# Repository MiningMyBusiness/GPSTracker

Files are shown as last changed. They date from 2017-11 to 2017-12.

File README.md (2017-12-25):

# GPS Tracker
Collection, visualization, and analysis of GPS data gathered with a homemade GPS module.

## Motivation
The concept of connectivity recives a lot of attention from a wide variety of fields. While we tend to reserve the main discussions about connectivity to the digital realm, I find myself drawn to the concept of connectivity in the physical world. Where we travel everyday and how we get there directly influences what we are exposed to and what is exposed to us. This has consequences for everything from disease epidemics to advertising. Moreover, such a record of movement would allow individuals to create an auxiliary memory of the history of places visited with great detail. Having access to this kind of information could have the potential for changing our sense of ourselves. 

For these reasons, I decided to track everywhere I go every day. I hope that this will give me an idea about how I move and where I go in this city, this country, and this world. Moreover, it will be a direct record of everywhere I have gone. I want to extract from this data the balance between my walking and using vehicular transport, my carbon footprint, and the geographical web in which I live my life. 

## Hardware
The homemade GPS module consists of Arduino Nano, an SD card module, an SD card, a passive ceramic GPS module, a 3.7V to 5V boost converter, and a LiPo battery. A schematic is shown below but more detail can be found in the [Hardware](https://github.com/MiningMyBusiness/GPSTracker/raw/master/Hardware) folder of the repository. The code used to program the Arduino can be found in the [Code](https://github.com/MiningMyBusiness/GPSTracker/raw/master/Code) folder of this repository.

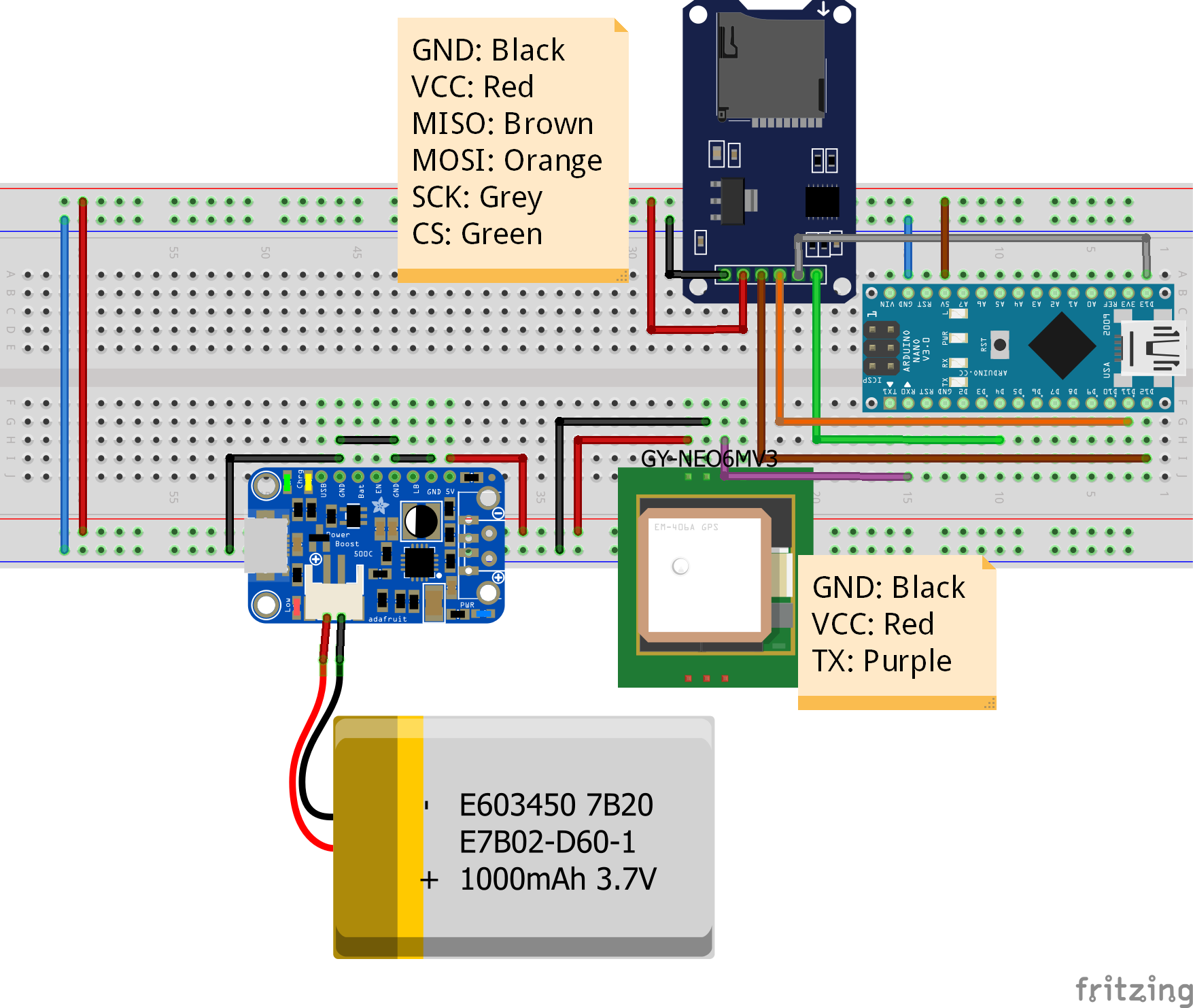
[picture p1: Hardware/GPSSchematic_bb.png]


I chose to make a homemade GPS over using the GPS in my smart phone. The cons of doing this include having to build and carry another piece of hardware. The pros include not having to worry about data plans, about your cell phone battery dying, about how your data may be held hostage or used by apps like [Swarm](https://en.wikipedia.org/wiki/Swarm_(app)), and the opportunity to learn something new. Additionally, since this homemade GPS module doesn't rely on cellular phone networks, it can track me anywhere in the world including in the middle of an ocean or a desert (assuming I go there). 

### Pilot hardware
I implemented the beta version of this hardware in a carboard Sparkfun box shown below (the mouse is in the image for comparison). This was adequately portable to collect pilot data. Use the mouse in the photo for size comparison.

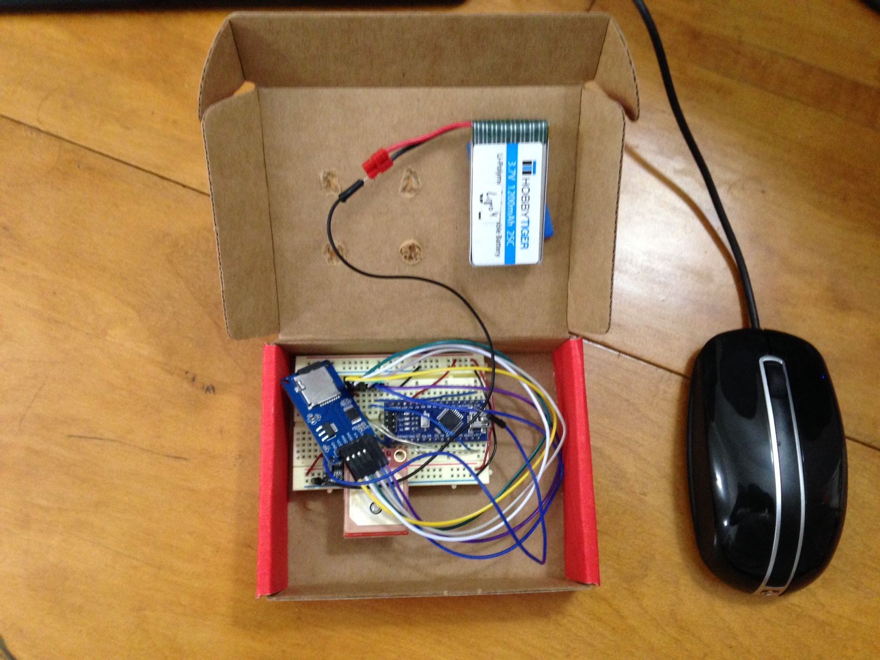
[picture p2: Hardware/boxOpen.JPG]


### Prototype hardware
I also made a much smaller version which I took with me when I travelled out of the country. The battery is blocking the view to the remainder of the parts.

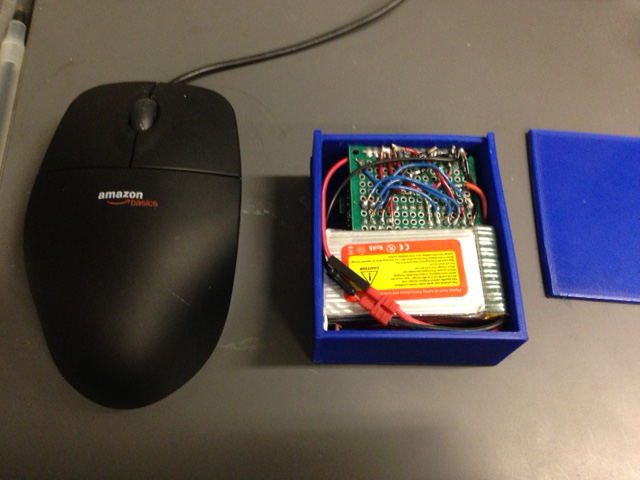
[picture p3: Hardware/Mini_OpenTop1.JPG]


More pictures of the smaller version and the .stl files for the 3D model of the box are provided in the [Hardware](https://github.com/MiningMyBusiness/GPSTracker/raw/master/Hardware) folder of the repository. This was tested on mountain roads between Bogota, Chaochi, and Ubaque in Colombia. These roads often do not have very dependable cell or data service. However, the main towns are well connected. 

## Data
The GPS module transmits recieved data to the Arduino. The Arduino writes this data to a text file in the SD card. Some lines in the text file might look like the following:

$GPRMC,070750.00,A,4200.31462,N,08739.74022,W,0.980,,251017,,,A*64 <br />
$GPVTG,,T,,M,0.980,N,1.815,K,A*2F <br />
$GPGGA,070750.00,4200.31462,N,08739.74022,W,1,03,4.76,257.7,M,-33.8,M,,*6D <br />
$GPGSA,A,2,16,27,08,,,,,,,,,,4.86,4.76,1.00*07 <br />
$GPGSV,1,1,04,08,68,076,33,16,13,068,35,27,34,047,23,33,04,102,33*70 <br />
$GPG076,33,16,13,068,34,27,34,047,23,33,04,102,32*70 <br />
$GPGLL,4200.31735,N,08739.74210,W,070755.00,A,A*7B <br />

Please take a look at the [Code](https://github.com/MiningMyBusiness/GPSTracker/raw/master/Code) in the repo to see how to make sense of this data. There is a [Python script](https://github.com/MiningMyBusiness/GPSTracker/raw/master/Code/gpsDataExtractor.py) in the [Code](https://github.com/MiningMyBusiness/GPSTracker/raw/master/Code) folder of the repository that parses through this data and organizes the date, time, latitude and longitude into lists. Then plots this data onto a Google roadmap and saves to an .html with zoom functionality. 

### Pilot data
I collected some data with the pilot hardware around Chicago as I went to work or went out to eat. Open the [html file](https://rawgit.com/MiningMyBusiness/GPSTracker/master/Results/mymap.html) to explore the dataset but I've also provided a static screenshot of the map below. 

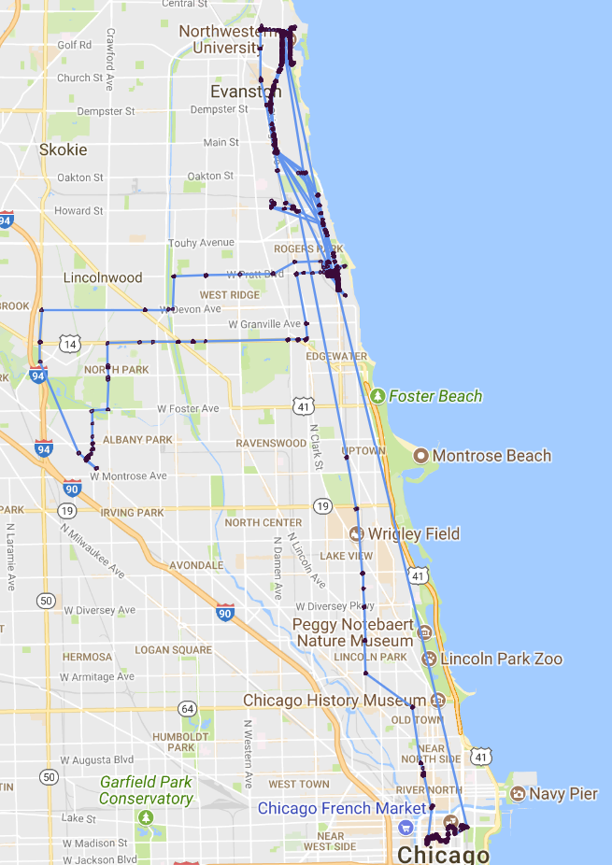
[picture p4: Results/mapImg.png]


### Data collected with prototype 
I took the smaller prototype in the blue box with me on my trip to Bogota, Colombia. I've provided a static screenshot of the map below from my trip to Colombia. Note that it is able to track in the middle of the mountains where there is poor cell/data service. 

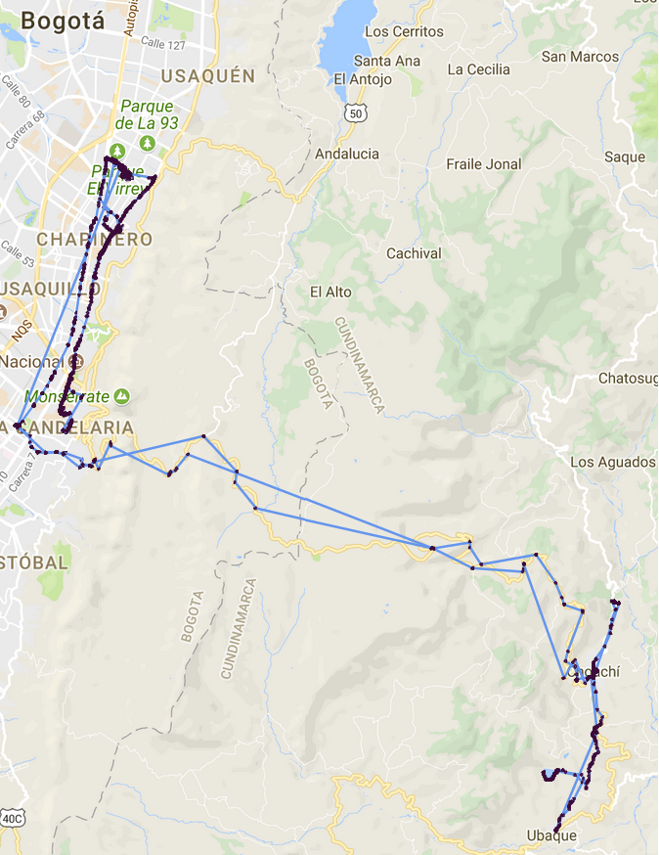
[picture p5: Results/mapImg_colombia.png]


## Work in progress
The next steps involve breaking this data into trips taken by day. Then using the speed of movement I can determine if I was walking or on vehicular transport. Potentially, by using locations where data is collected I can also determine if I was using the L-train.

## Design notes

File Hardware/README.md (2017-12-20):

# Hardware build descriptions
This folder and ReadMe contains relevant information about how to build the GPS module. 

### Parts list
To build the GPS module as described here you will need the following parts:

1. [Arduino Nano](https://www.amazon.com/gp/product/B0713XK923/ref=oh_aui_search_detailpage?ie=UTF8&psc=1)
2. [GPS module](https://www.amazon.com/gp/product/B01AW5QYES/ref=oh_aui_search_detailpage?ie=UTF8&psc=1)
3. [SD card module](https://www.amazon.com/gp/product/B01JYNEX56/ref=oh_aui_search_detailpage?ie=UTF8&psc=1)
4. [SD card](https://www.amazon.com/SanDisk-Memory-SDSDUN-008G-G46-Newest-Version/dp/B00M55BS5O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)
5. [3.7V Lipo battery](https://www.amazon.com/gp/product/B01HG7TYNI/ref=oh_aui_detailpage_o03_s00?ie=UTF8&psc=1)
6. [3.7V to 5V boost converter](https://www.amazon.com/gp/product/B01LW57OUM/ref=oh_aui_detailpage_o07_s00?ie=UTF8&psc=1)

Each part name is a link to the Amazon page for the parts I used to make my module. However, you do not need to adhere exactly to these parts.

### Schematic
The images below represent the wiring of all components in two different ways.

1. A breadboard view with cartoon representation of components made with [Fritzing](http://fritzing.org/home/).


2. A circuit diagram of the wiring of components also made with Fritzing. 
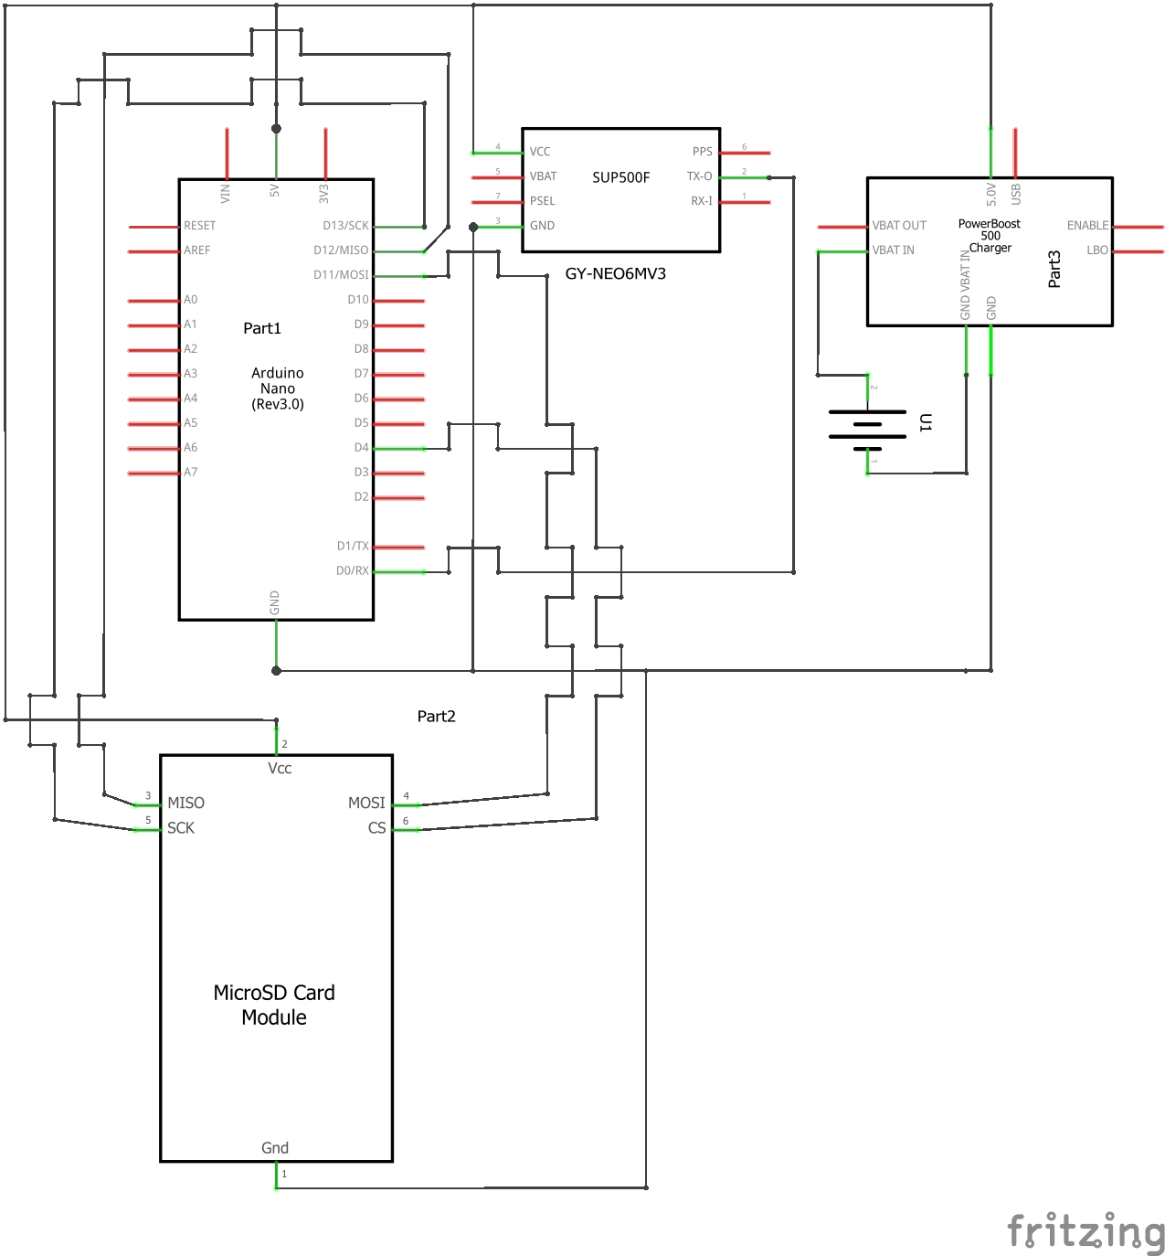
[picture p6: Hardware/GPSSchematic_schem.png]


I used a different 3.7V to 5V boost converter than the one shown in the schematic (link is provided in parts list above) which was a lot simpler and cheaper. 

IMPORTANT NOTE: Do not have the GPS module powered and connected to the RX pin of the Arduino when uploading code onto the Arduino. This will interfere with uploading code onto the Arduino. Power the GPS module after the code has been uploaded onto the Arduino. 

### Initial pilot version
I've attached some images which show the prototype I made to collect some pilot data and test feasibility of this project. The computer mouse in the image provides a size comparison with the prototype. 

1. Innards


2. Top view
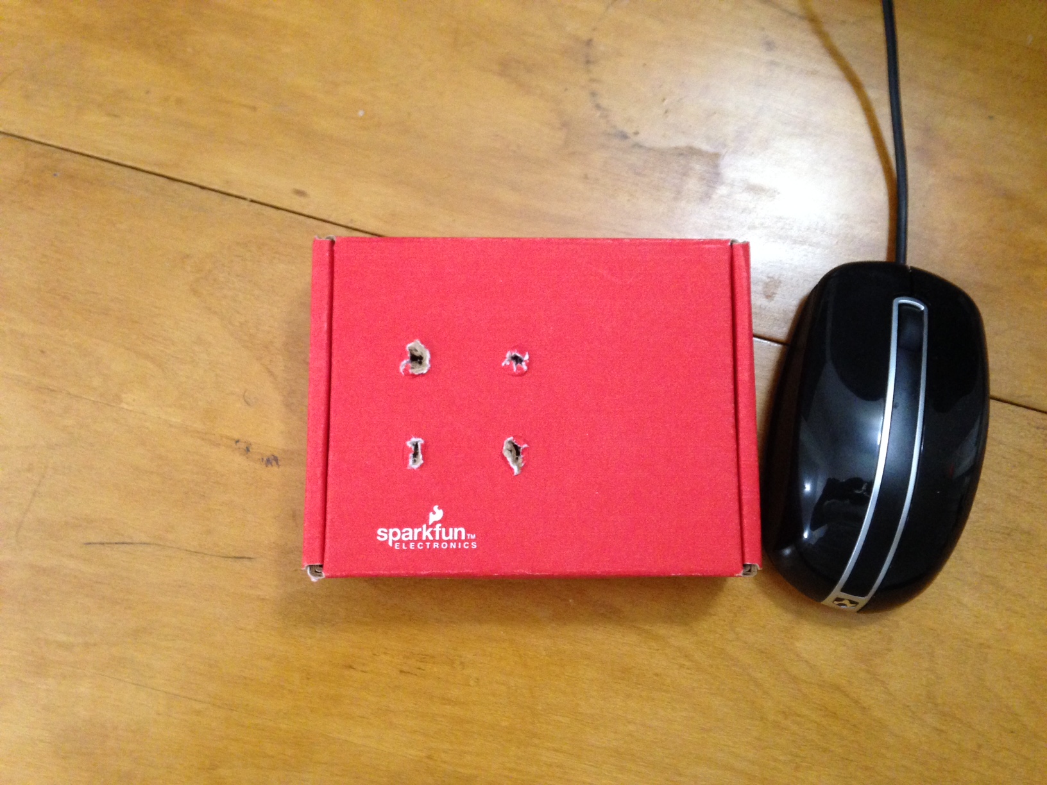
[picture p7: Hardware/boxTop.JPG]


3. Side view
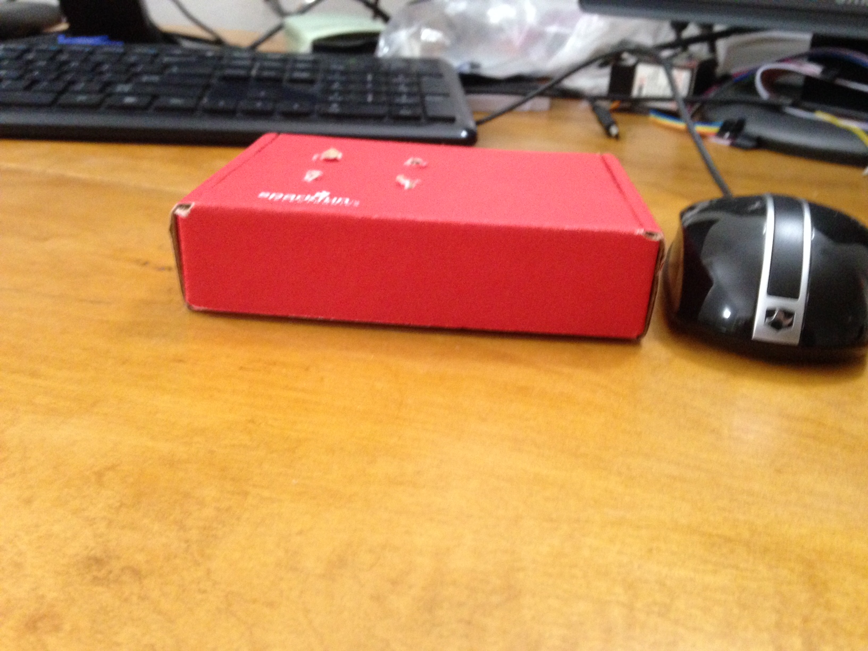
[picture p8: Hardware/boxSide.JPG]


### Prototype version
I miniaturized this further and soldered components onto a smaller board. This was then inserted into a project box 3D printed with an Ultimaker 3. Again use the mouse for size comparison. This is much smaller than the pilot verison. 

1. Box model 
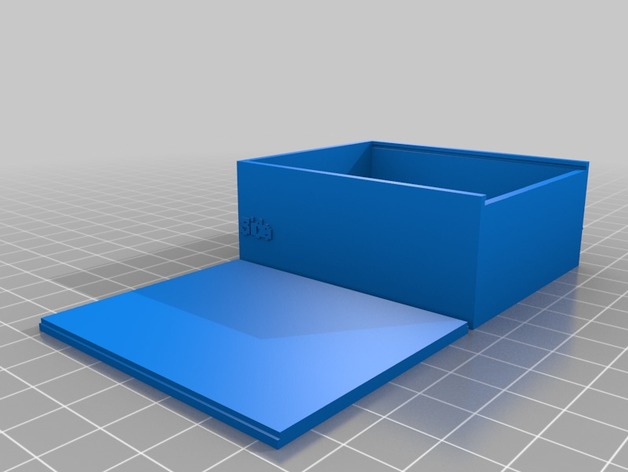
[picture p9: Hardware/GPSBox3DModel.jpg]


2. Closed top 
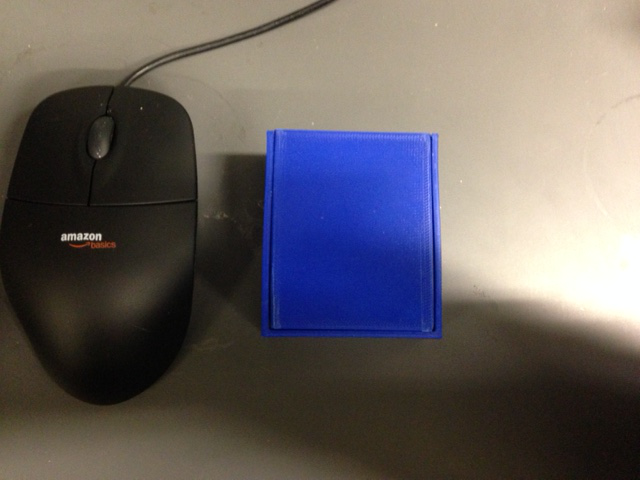
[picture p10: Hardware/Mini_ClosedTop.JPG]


3. Open top


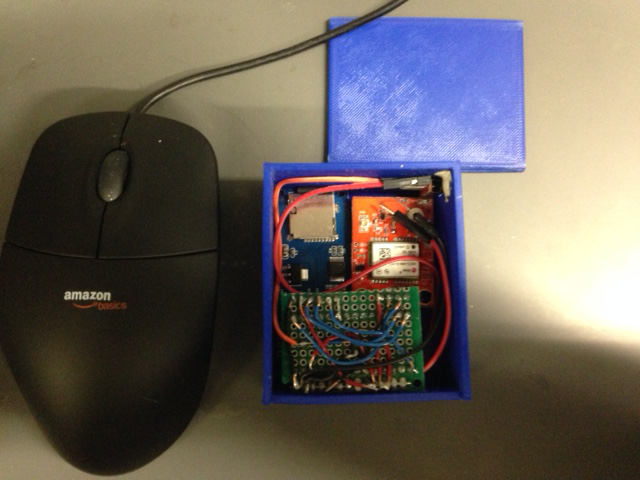
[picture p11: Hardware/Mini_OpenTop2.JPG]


4. Taken apart 
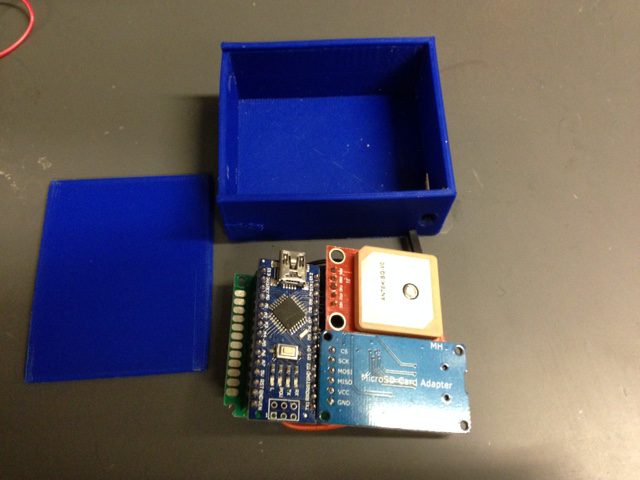
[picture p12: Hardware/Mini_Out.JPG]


### Tips for hardware replication
I would HIGHLY recommend building this project in pieces and troubleshooting along the way. These are some webpages I found to be very useful. 

- [SD card notes](https://www.arduino.cc/en/Reference/SDCardNotes)
- [SD card read/write](https://www.arduino.cc/en/Tutorial/ReadWrite)

I would not recommend trying to use the SoftwareSerial library with the GPS module. I found that it did not work well for me.

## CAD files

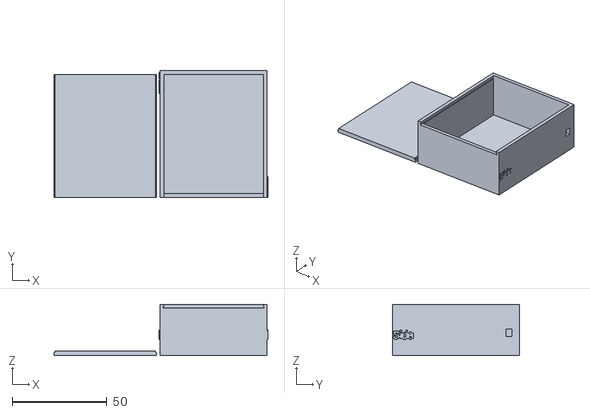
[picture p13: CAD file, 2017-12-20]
Hardware/GPSBox3DModel.stl
113.0 x 67.0 x 27.0

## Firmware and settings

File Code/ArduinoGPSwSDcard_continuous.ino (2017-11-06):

// Grabs data from GPS module and writes to an SD card every 5 seconds.
//
// License: MIT License
//
// Author: Kiran Bhattacharyya (bhattacharyyakiran12@gmail.com)   


// include relevant libraries
#include <SPI.h> 
#include <SD.h>

int chipSelect = 4; // set the digital out pin to connect to SD card module chip select
 
void setup() {

  //Being serial communication with Arduino and GPS Module //Important rate must be 9600
  Serial.begin(9600);
  
  // see if the card is present and can be initialized:
  if (!SD.begin(chipSelect)) {
    // don't do anything more:
    return;
  }    
}
 
void loop() {

  byte pbyGpsBuffer[500]; // initialize a variable to store GPS data 
  int byBufferIndex = 0; // initialize an indexing variable

  while (byBufferIndex < 500) { // while indexing variable is smaller than index available in storing variable
    
    //Read output of GPS (if available) and save in a buffer
    if (Serial.available()) {
      pbyGpsBuffer[byBufferIndex ++] = Serial.read(); // put data in buffer
    }
  }

  File myFile = SD.open("gps.txt", FILE_WRITE); // open file in SD card
    
  if (myFile) { // if file opens 
    myFile.write(pbyGpsBuffer, byBufferIndex); // then write data
    myFile.close(); // close the file 
  }

  delay(5000); // delay 5 seconds before relooping
  
}
